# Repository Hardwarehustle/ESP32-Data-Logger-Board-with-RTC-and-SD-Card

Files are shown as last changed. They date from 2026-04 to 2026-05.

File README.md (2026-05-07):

# ESP32 Data Logger Board with RTC and SD Card

> Designed by: Janardhan BV  
> Tool: EasyEDA  
> Revision: 1.0  
> Date: 2024-07-07

## Project Overview

This project is a compact **ESP32-based controller board** that combines wireless processing, USB programming, removable storage, and a battery-backed real-time clock on a single PCB. [file:147] It is structured around five clear hardware blocks in the schematic: **ESP32 module**, **power supply**, **USB-to-UART bridge**, **SD card connector**, and **RTC**. [file:147]

The board is suitable for applications such as IoT data logging, time-stamped sensor recording, edge monitoring, and embedded control where local storage and persistent timekeeping are required. [file:147]

## Key Features

- ESP32 module as the main controller with exposed programming and interface signals. [file:147]
- USB-to-UART bridge for firmware upload and serial debugging. [file:147]
- Auto-reset / auto-boot circuit using DTR and RTS so the ESP32 can enter bootloader mode during flashing without manual intervention. [file:147][web:41]
- Onboard 3.3V regulation using an **AMS1117-3.3** style power stage. [file:147][web:152]
- Dedicated SD card connector for local data logging. [file:147]
- Battery-backed RTC section for maintaining time when main power is removed. [file:147]

## Project Visuals

### Schematic
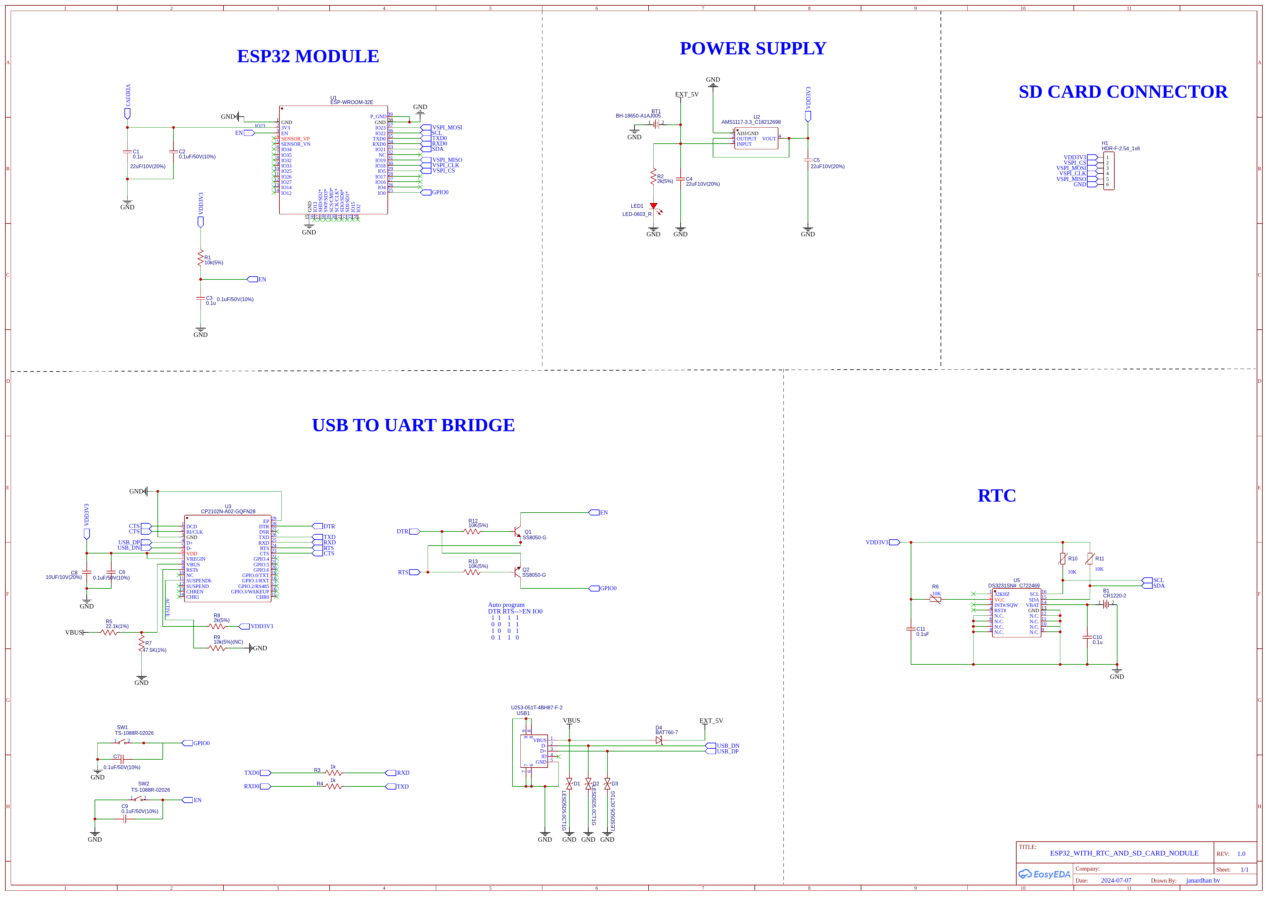
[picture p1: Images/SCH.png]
Schematic


### PCB Layout
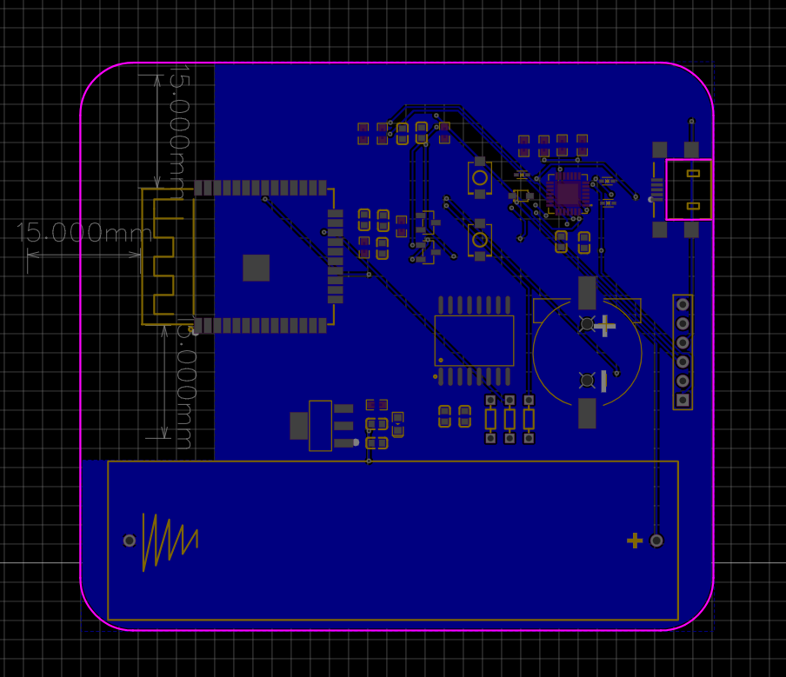
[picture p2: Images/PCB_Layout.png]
PCB Layout


### 3D Board Top View
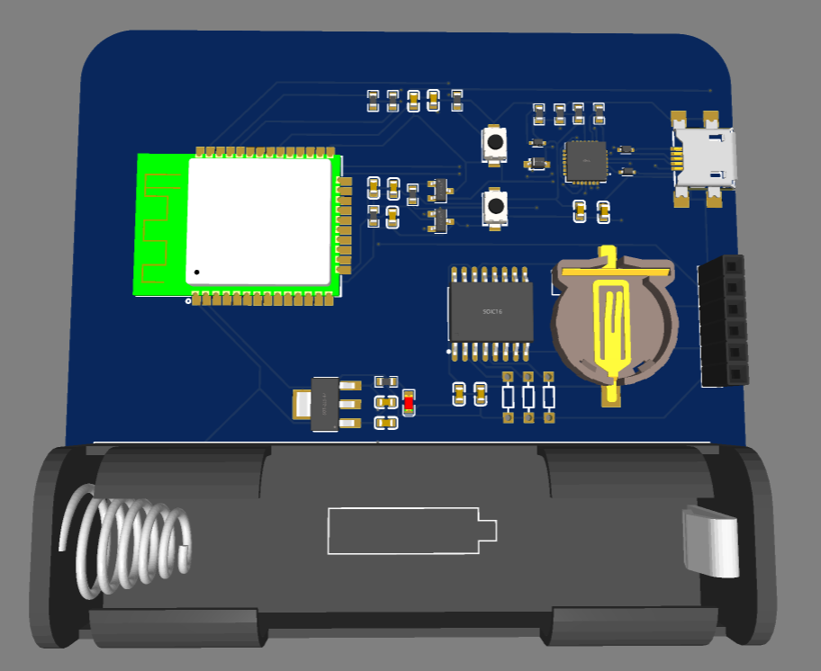
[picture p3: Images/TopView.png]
3D Top View


### 3D Board Bottom View
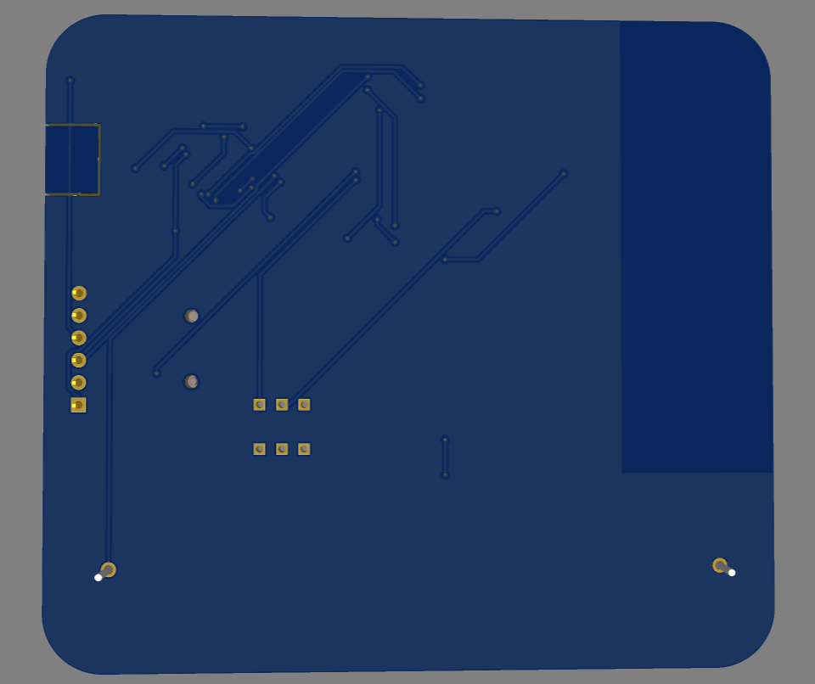
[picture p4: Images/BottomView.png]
3D Bottom View
	

## Hardware Blocks

### ESP32 Module

The ESP32 section is the core compute block of the design and is connected to power, boot/reset control, serial programming lines, and external interfaces. [file:147] The schematic shows the usual EN and IO0 control needed for programming and startup behavior. [file:147]

### USB-to-UART Bridge

A CP2102-style USB-to-UART bridge is used to connect the board to a computer for code upload and serial communication. [file:147][web:156] The DTR and RTS signals are routed through a transistor-based auto-programming circuit, which matches the common ESP32 flashing method used by development boards. [file:147][web:41]

### Power Supply

The power section uses an AMS1117-3.3 regulator block with filtering components and indicator LED support to generate the main 3.3V rail for the board. [file:147][web:152] The schematic also shows external 5V input routing and USB power entry into the board power domain. [file:147]

### SD Card Interface

The SD card block provides a dedicated connector for removable storage, intended for logging files, measurement records, or configuration data. [file:147] This makes the board useful for standalone systems that must store data locally without a constant wireless connection. [file:147]

### RTC Section

The RTC portion includes an I2C clock device, support passives, and a backup coin-cell connection so time can be retained during power loss. [file:147] This allows the ESP32 to attach timestamps to measurements, events, or log files after reboot. [file:147]

## Programming and Boot Control

The programming section includes EN and IO0 control through the USB bridge handshake lines, which is the standard mechanism used for ESP32 automatic upload. [file:147][web:41] In typical ESP32 reset logic, DTR and RTS are toggled so EN is pulsed and IO0 is held low at the correct moment, forcing the chip into bootloader mode for flashing. [web:41]

## PCB Notes

The board layout reserves a large clear region around the RF side of the ESP32 module, which is good practice for antenna performance. [file:146][file:147] The design appears to be a compact two-layer board with short signal paths between the ESP32, USB bridge, RTC, and SD card sections. [file:146][file:147]

## Typical Applications

- IoT event logger. [file:147]
- Time-stamped sensor node. [file:147]
- Wi-Fi or Bluetooth data recorder with SD backup. [file:147]
- Compact controller board for embedded prototypes needing RTC and storage. [file:147]

## Bring-Up Checklist

1. Verify the 5V input rail before powering the ESP32 section. [file:147]
2. Confirm the AMS1117 output is a stable 3.3V. [file:147][web:152]
3. Check EN and IO0 behavior during USB flashing. [file:147][web:41]
4. Test serial communication through the USB-to-UART bridge. [file:147][web:156]
5. Verify RTC communication over I2C and confirm backup time retention. [file:147]
6. Insert an SD card and validate read/write operation from firmware. [file:147]

## Future Improvements

- Add clear silkscreen labels for all external headers. [file:146][file:147]
- Add test points for 5V, 3.3V, EN, IO0, TX, and RX. [file:147]
- Add ESD and surge review on the USB and external power input if the board will be used in field deployments. [file:147]

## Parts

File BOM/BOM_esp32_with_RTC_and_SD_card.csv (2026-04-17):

ID | Name | Designator | Footprint | Quantity | Manufacturer Part | Manufacturer | Supplier | Supplier Part | Price
1 | 0.1u | C1,C3,C5,C10 | C0603 | 4
2 | 0.1uF/50V(10%) | C2,C6,C7,C9 | C0603 | 4
3 | 22uF10V(20%) | C4 | C0603 | 1
4 | 10UF/10V(20%) | C8 | C0603 | 1
5 | 0.1uF | C11 | C0603 | 1
6 | CR1220-2 | B1 | BAT-SMD_CR1220-2 | 1 | CR1220-2 | Q&J | LCSC | C70381 | 0.231
7 | BH-18650-A1AJ005 | BT1 | BAT-TH_BH-18650-A1AJ005 | 1 | BH-18650-A1AJ005 | MYOUNG(美阳) | LCSC | C5290176 | 0.526
8 | LESD5D5.0CT1G | D1,D2,D3 | SOD-523_L1.2-W0.8-LS1.6-BI | 3 | LESD5D5.0CT1G | LRC(乐山无线电) | LCSC | C383211 | 0.016
9 | BAT760-7 | D4 | SOD-323_L1.8-W1.3-LS2.5-RD | 1 | BAT760-7 | DIODES(美台) | LCSC | C124187 | 0.052
10 | HDR-F-2.54_1x6 | H1 | HDR-F-2.54_1X6 | 1 |  |  | LCSC | C40877 | 0.088
11 | LED-0603_R | LED1 | LED0603_RED | 1 | 19-217/R6C-AL1M2VY/3T | EVERLIGHT(台湾亿光) | LCSC | C72044 | 0.021
12 | SS8050-G | Q1,Q2 | SOT-23-3_L2.9-W1.3-P1.90-LS2.4-BR | 2 | SS8050-G | CJ(江苏长电/长晶) | LCSC | C164886 | 0.016
13 | 10k(5%) | R1 | R0603 | 1
14 | 2k(5%) | R2,R8 | R0603 | 2
15 | 1k | R3,R4 | R0603 | 2
16 | 22.1k(1%) | R5 | R0603 | 1
17 | 47.5K(1%) | R7 | R0603 | 1
18 | 10k(5%)(NC) | R9 | R0603 | 1
19 | 10K(5%) | R12,R13 | R0603 | 2
20 | VARISTOR-5 | R6,R10,R11 | R-5 | 3
21 | TS-1088R-02026 | SW1,SW2 | SW-SMD_L3.9-W3.0-P4.45 | 2 | TS-1088R-02026 | XUNPU(讯普) | LCSC | C455280 | 0.06
22 | ESP-WROOM-32E | U1 | COMM-SMD_ESP-WROOM-32D | 1 | ESP-WROOM-32E | DOIT(四博智联) | LCSC | C19949066 | 3.137
23 | AMS1117-3.3_C18212698 | U2 | SOT-223-3_L6.5-W3.4-P2.30-LS7.0-BR | 1 | AMS1117-3.3 | TECH PUBLIC(台舟) | LCSC | C18212698 | 0.044
24 | CP2102N-A02-GQFN28 | U3 | QFN-28_L5.0-W5.0-P0.50-TL-EP3.3 | 1 | CP2102N-A02-GQFN28 | SKYWORKS/SILICON LABS(芯科) | LCSC | C1550553 | 2.365
25 | DS3231SN#_C722469 | U5 | SOIC-16_L10.3-W7.5-P1.27-LS10.3-BL | 1 | DS3231SN# | ADI(亚德诺)/MAXIM(美信) | LCSC | C722469 | 7.869
26 | U253-051T-4BH87-F-2 | USB1 | MICRO-USB-SMD_U253-051T-4BH87-S-2 | 1 | U253-051T-4BH87-S2 | XKB Connectivity(中国星坤) | LCSC | C319174 | 0.078

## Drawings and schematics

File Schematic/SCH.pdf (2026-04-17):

# IO12 14IO14 13IO27 12IO26 11IO25 10IO33 9

# POWER SUPPLY

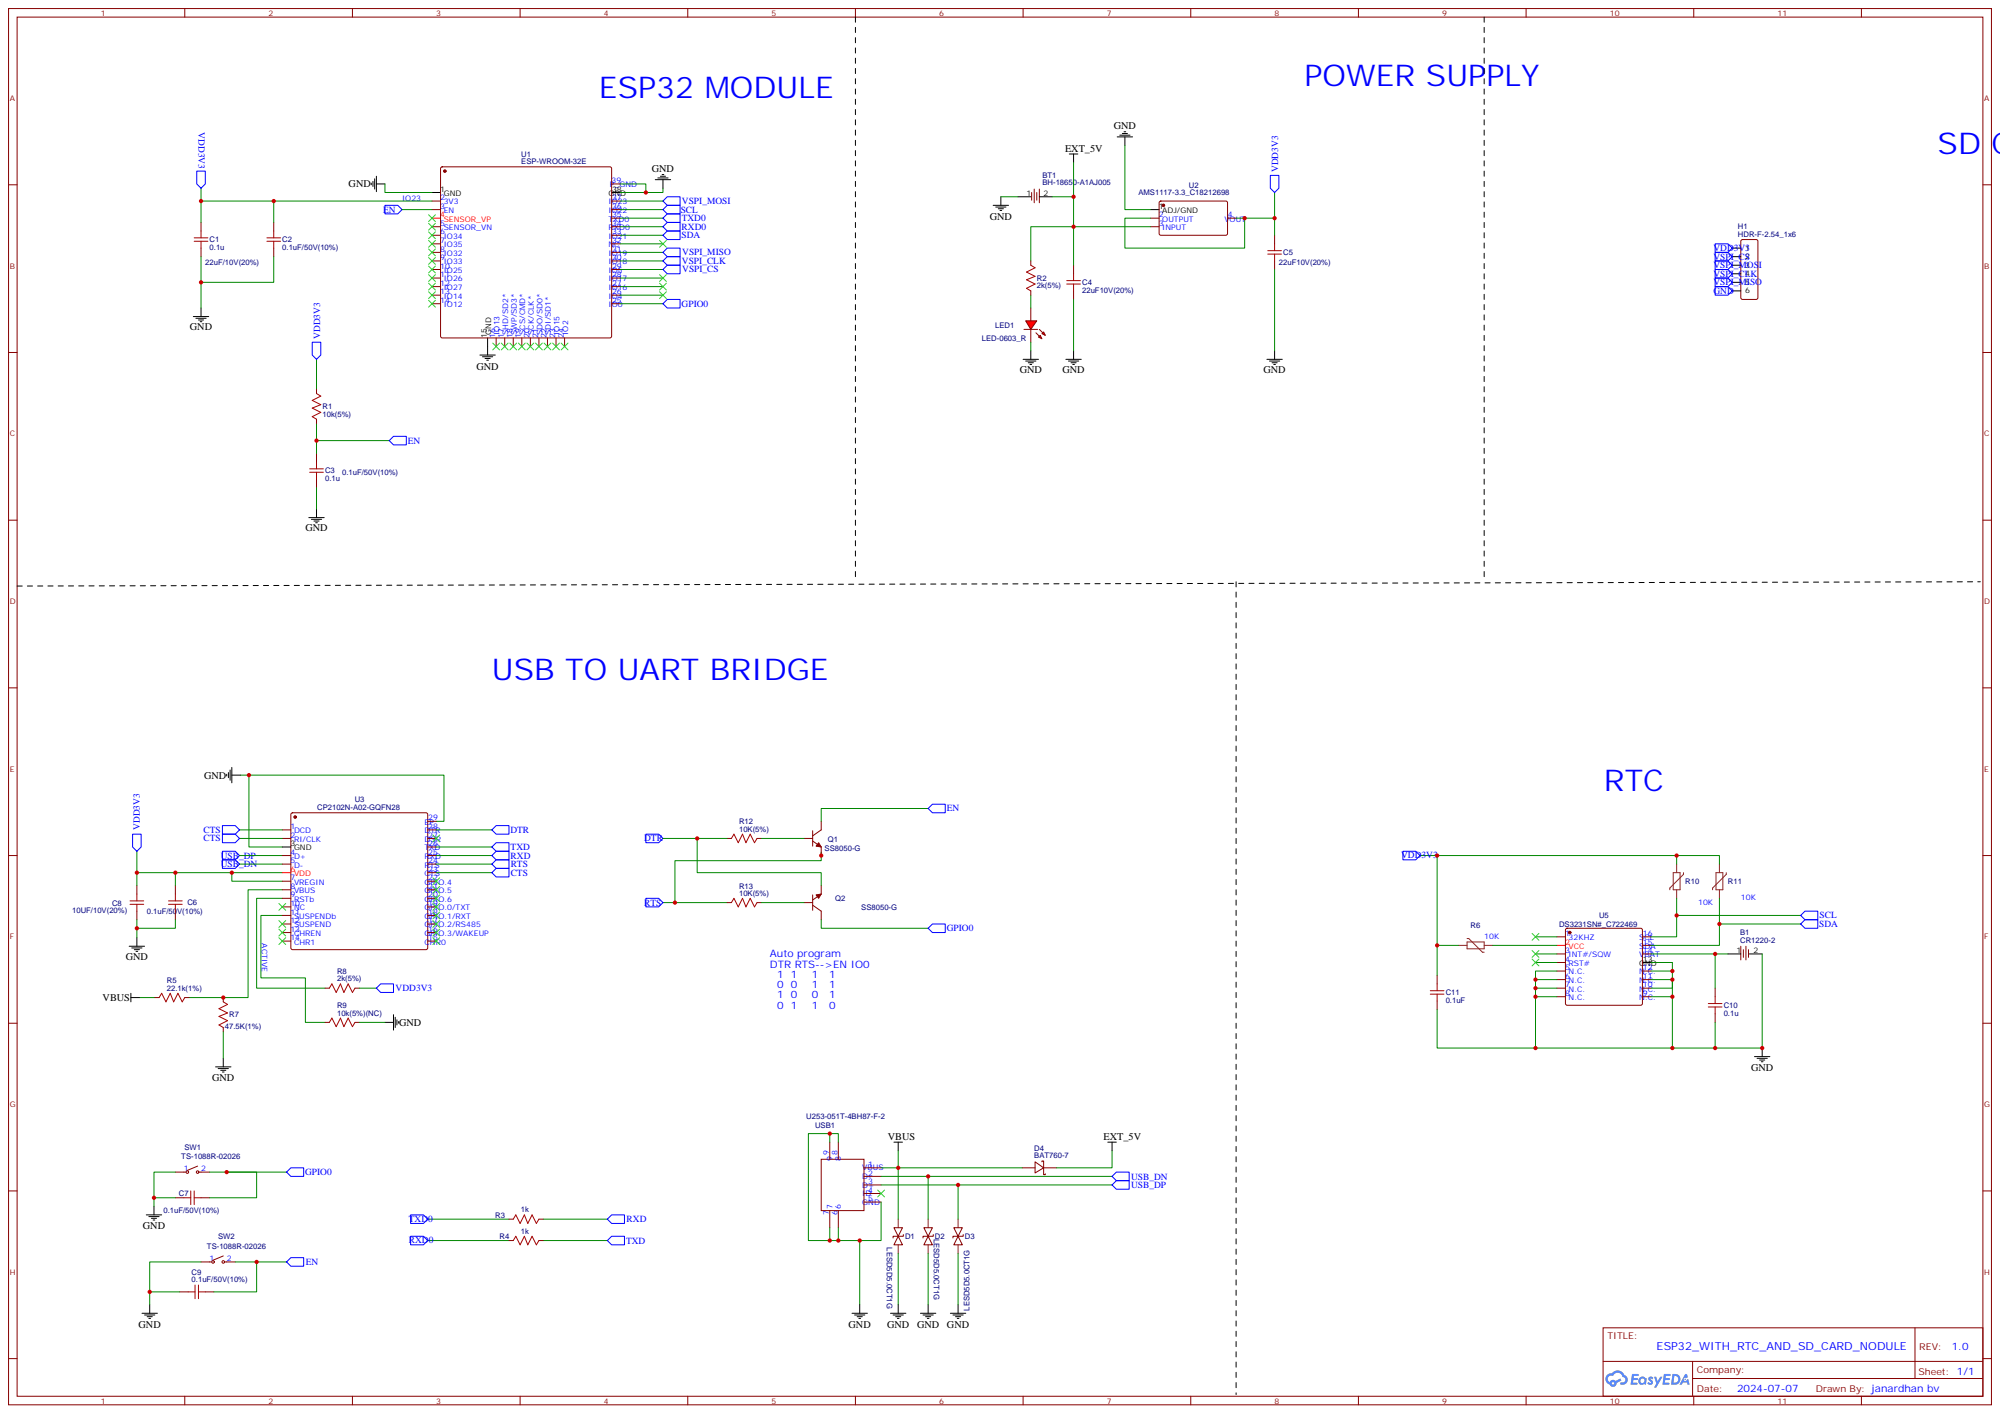
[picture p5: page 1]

USB TO UART BRIDGE

Drawn By: janardhan bv

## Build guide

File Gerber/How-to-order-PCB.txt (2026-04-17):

How to Order PCB

Please refer to:
https://docs.easyeda.com/en/PCB/Order-PCB
